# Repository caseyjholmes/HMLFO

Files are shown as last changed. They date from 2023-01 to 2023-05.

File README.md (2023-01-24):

# HMLFO
Holmes Modular 2HP Eurorack Module Version of Niklas Rohnnberg's Analog LFO.. with PSI Power 

These are simple board files for a PCB and a panel for a small analog 2HP Eurorack format synthesizer LFO Module with reversible power input. 
Just print yourself some PCB's and add the parts then adjust the trimmer while you connect the outputs to an oscilloscope to calibrate. 

Build Notes:
If the trim pot isn't adjusted right, the circuit won't run properly. Don't be scared if it doesn't cycle intiailly. It needs calibration. Hook the outputs to an oscilloscope and mess with the trim pot. You can get 5 - 10V operation if you tune it some.

Use MTS-102 switches on ebay. You'll need to file down the tiny plastic nubs on the botton with a needle file to get the switches to fit at the same height as the jacks and pots, but it is very much possible. 

BE SURE TO PAY SPECIAL ATTENTION TO THE VALUES OF THE POTENTIOMETERS. YOU HAVE BEEN WARNED! 

You may change C1 and C5 to adjust the LFO rates that are selectable via the switch. 
Enjoy!
-Casey

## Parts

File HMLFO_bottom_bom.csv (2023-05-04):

Comment | Designator | Footprint | LCSC Part #
1N4148 | D1 D2 | SOD-323F
1k | R7 | R0603
10uf | C5 | C0805K
47k | R5 R6 | R0603
100k | R1 | R0603
100n | C1 C3 C4 | C0603K
220 | R2 | R0603
MB1S | B1 | SOIC-4
TL072_SMD | U1 | SO08
mmbt3904 | T1 | SOT23-BEC

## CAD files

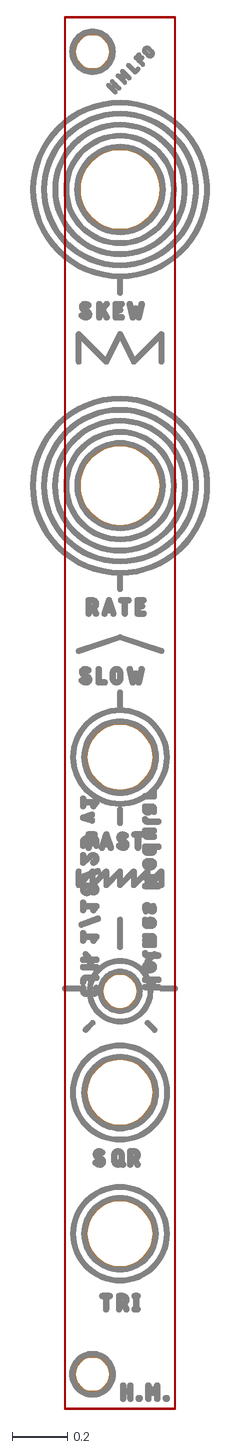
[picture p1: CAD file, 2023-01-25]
HMLFOpanelV2.dxf
0.652 x 5.06

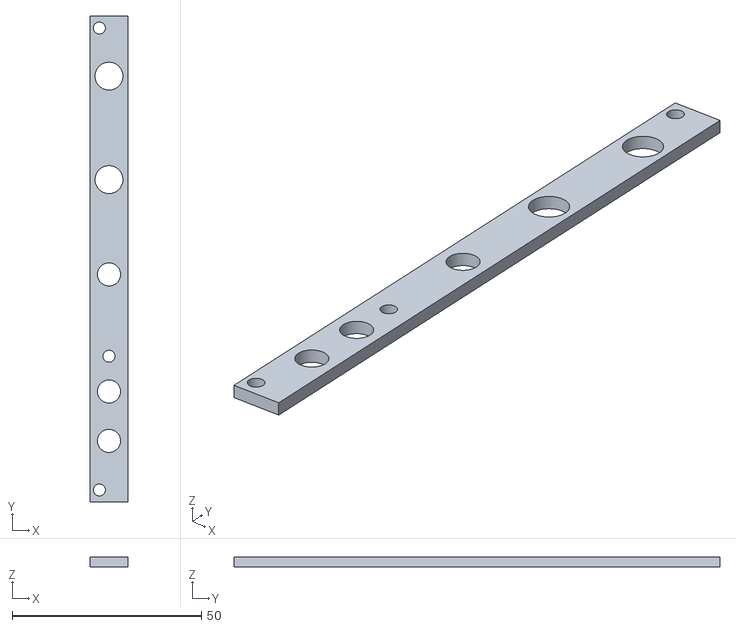
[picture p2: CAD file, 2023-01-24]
HMLFO 3D panel.stl
10.2 x 128.3 x 2.54

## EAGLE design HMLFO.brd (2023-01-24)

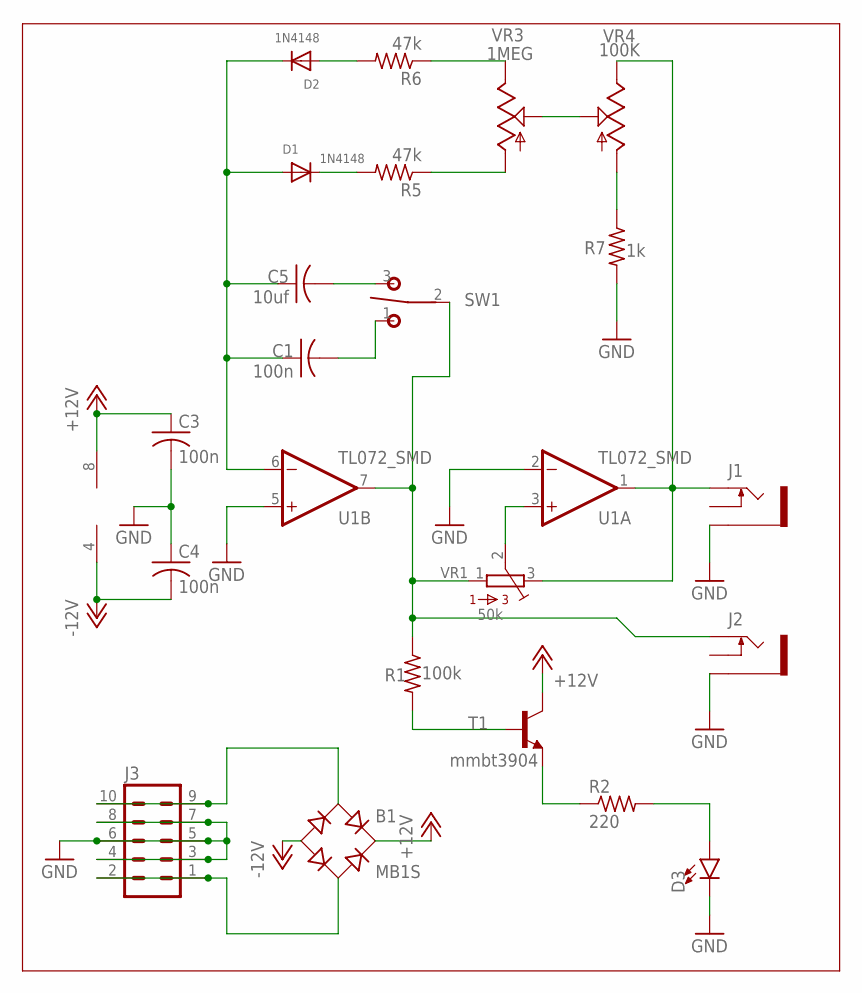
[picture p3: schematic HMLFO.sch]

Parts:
B1: MB1S; SOIC-4
C1, C3, C4: 100n; C0603K
C5: 10uf; C0805K
D1, D2: 1N4148; SOD-323F
D3: LED3MM; LED_3MM
J1, J2: THONKICONNNEW; WQP-PJ301M-12_JACK
J3: MA05-2
R1: 100k; R0603
R2: 220; R0603
R5, R6: 47k; R0603
R7: 1k; R0603
SW1: T-80-T-SPDT-ON-OFF-ON; M9040P
T1: mmbt3904; SOT23-BEC
U1: TL072_SMD; SO08
VR1: 50k; BOURNS_3362P_TRIMMER
VR3: 1MEG; 9MM_SNAP-IN_POT
VR4: 100K; 9MM_SNAP-IN_POT

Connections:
+12V: B1.+, C3.1, T1.C, U1.8 (V+)
-12V: B1.-, C4.2, U1.4 (V-)
GND: C3.2, C4.1, D3.K (C), J1.P$3_SLEEVE (SLEEVE), J2.P$3_SLEEVE (SLEEVE), J3.3, J3.4, J3.5, J3.6, J3.7, J3.8, R7.2, U1.2 (-IN), U1.5 (+IN)
unnamed: C1.1, C5.1, D1.A, D2.C, U1.6 (-IN)
unnamed: VR3.2 (S), VR4.2 (S)
unnamed: R6.1, VR3.3 (E)
unnamed: R5.1, VR3.1 (A)
unnamed: D1.C, R5.2
unnamed: D2.A, R6.2
unnamed: U1.3 (+IN), VR1.2
unnamed: J2.P$1_TIP (TIP), R1.1, SW1.2, U1.7 (OUT), VR1.1
unnamed: J1.P$1_TIP (TIP), U1.1 (OUT), VR1.3, VR4.3 (E)
unnamed: R7.1, VR4.1 (A)
unnamed: R1.2, T1.B
unnamed: R2.1, T1.E
unnamed: D3.A, R2.2
unnamed: C1.2, SW1.1 (O)
unnamed: C5.2, SW1.3 (S)
unnamed: B1.~1 (AC1), J3.9, J3.10
unnamed: B1.~2 (AC2), J3.1, J3.2

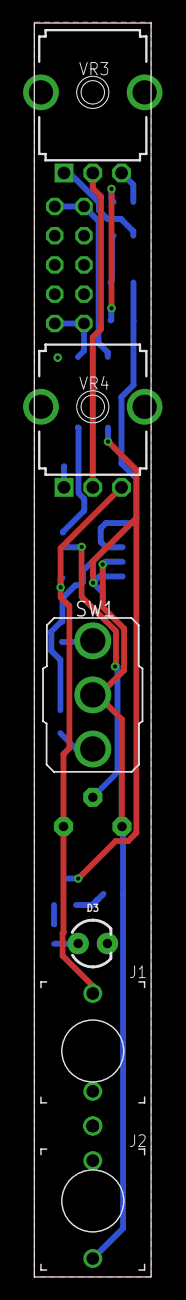
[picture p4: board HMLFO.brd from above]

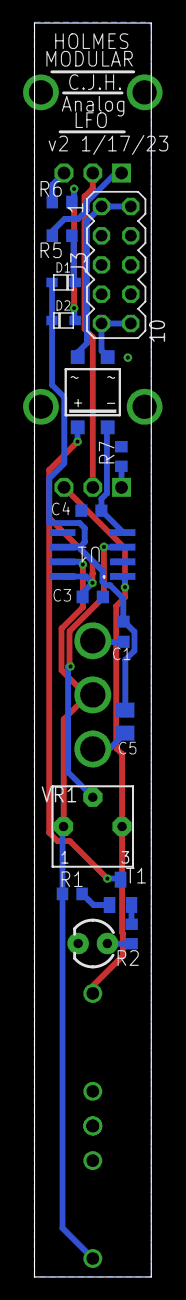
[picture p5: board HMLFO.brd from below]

Board: 2 copper layers, 10.1 x 108.9 mm, 22 parts (16 on the bottom side), 20 nets.

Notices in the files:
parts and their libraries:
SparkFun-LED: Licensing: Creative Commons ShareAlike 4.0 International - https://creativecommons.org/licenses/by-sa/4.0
